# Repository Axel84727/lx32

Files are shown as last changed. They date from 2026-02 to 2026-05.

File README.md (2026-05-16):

# lx32

I built a computer from scratch because ChatGPT told me "no hay huevos." So here we are.

Custom processor, custom PCB, custom compiler. The whole thing.

---

## ok first let me flex

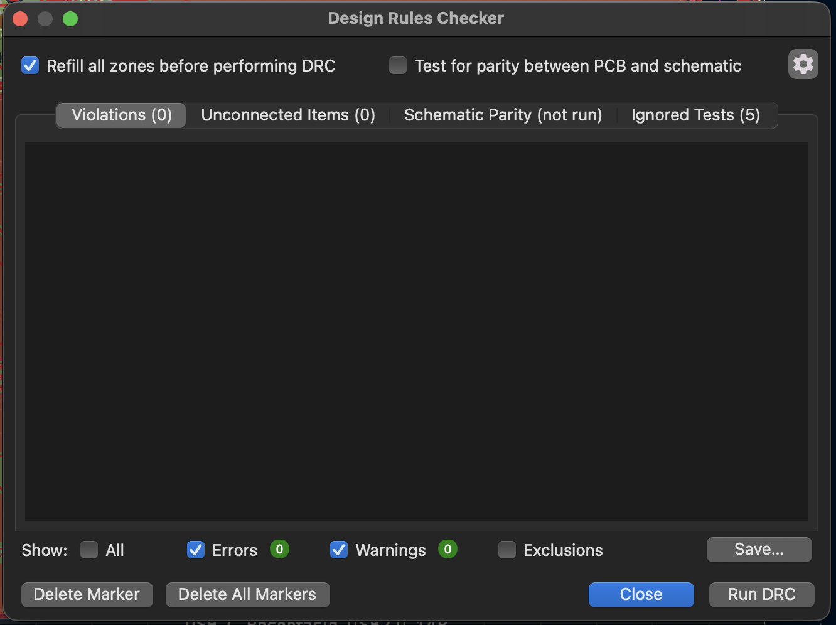
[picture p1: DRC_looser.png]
looser


Zero violations. Zero unconnected items. I cried a little.

(also this is the 5th time I rewrote this README. if it still looks AI-generated I give up)

---

## what is this actually

lx32 is a 32-bit CPU with a custom instruction set, running on a custom PCB, compiled by a custom LLVM backend. You can write C, compile it, and it runs on this thing.

I wanted to actually understand how computers work, not just read about it. So I built one.

The board is 80x60mm, about the size of a credit card. Black soldermask, gold finish.

---

## the board

Here's what it looks like:

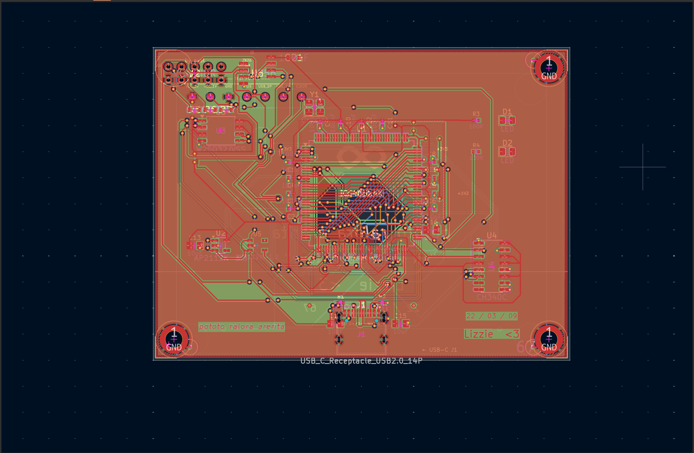
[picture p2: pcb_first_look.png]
first look


The schematics:

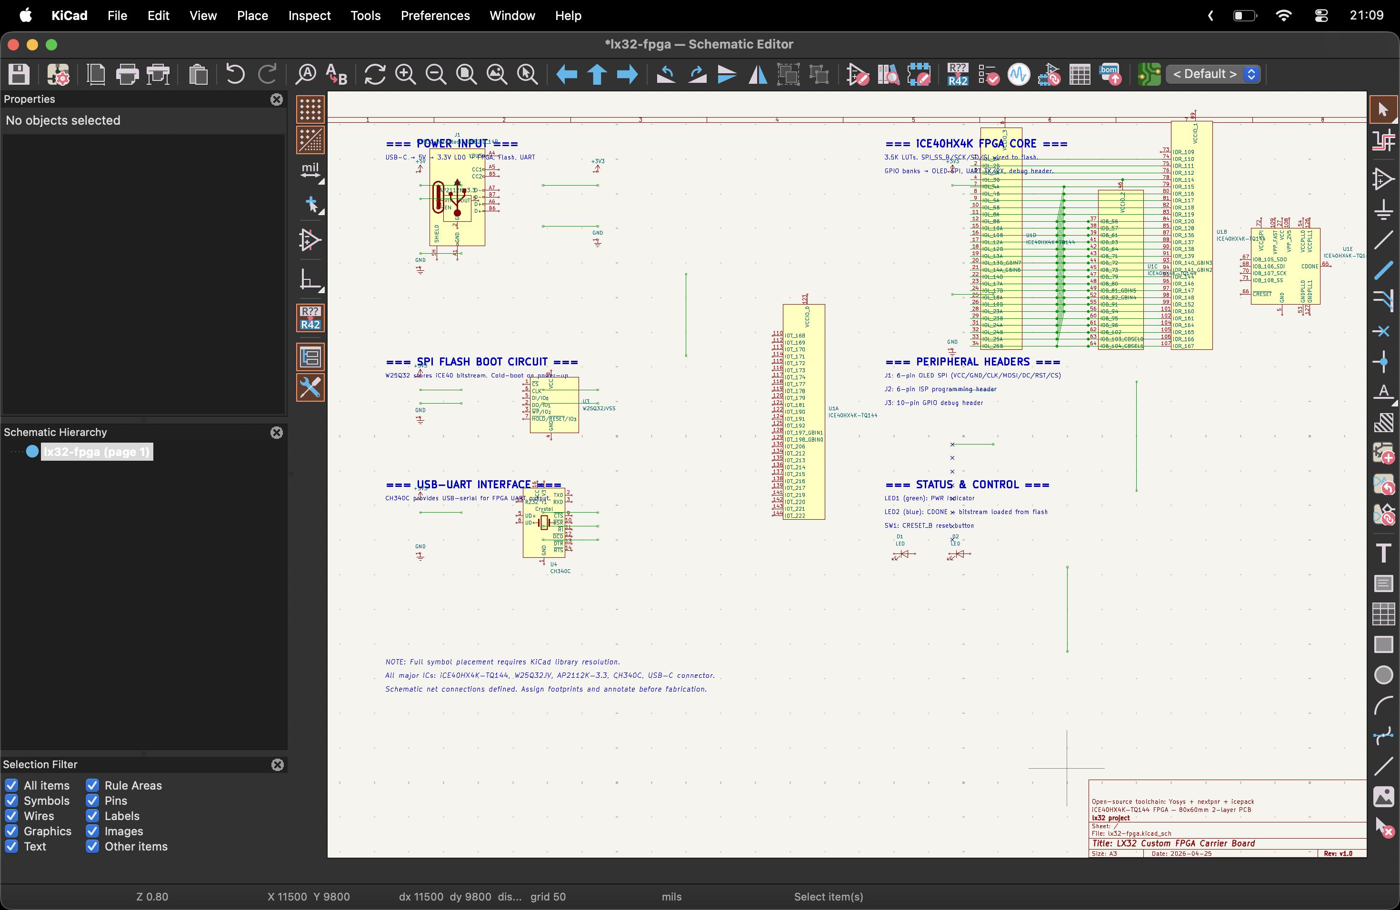
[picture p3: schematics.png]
schematics


Measurements:

Long:
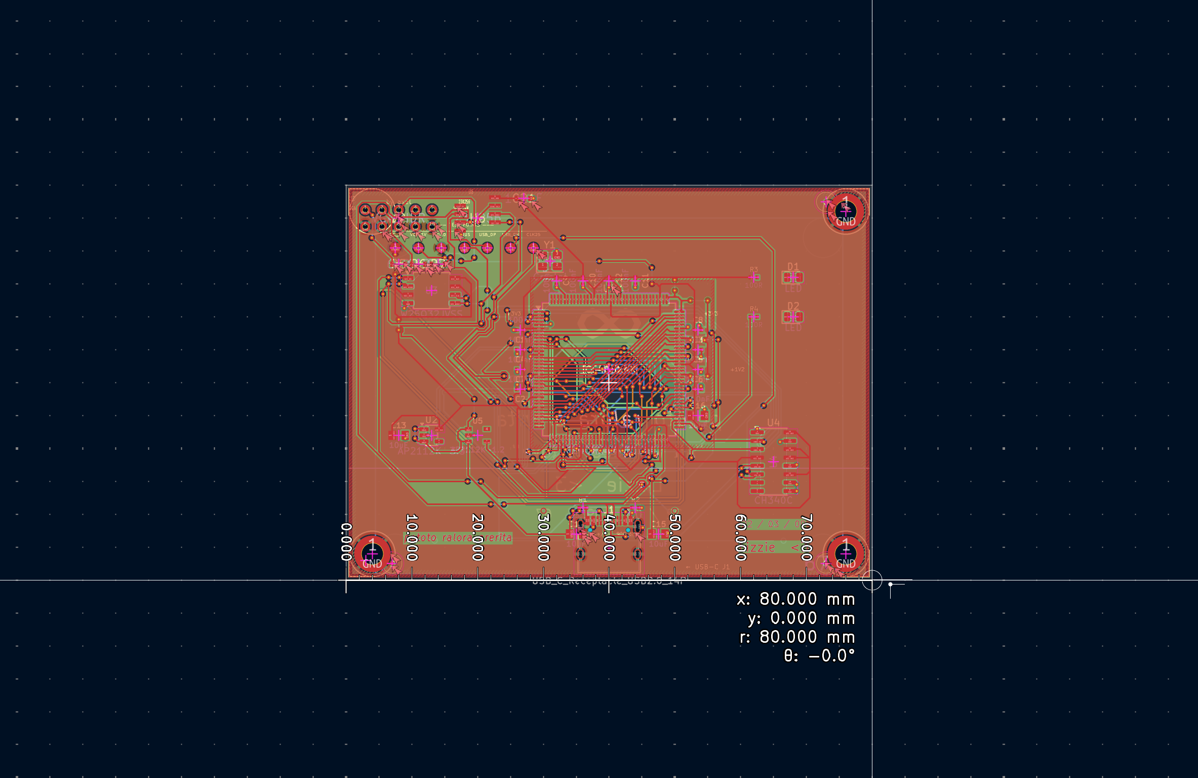
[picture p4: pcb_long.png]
pcb long


Width:
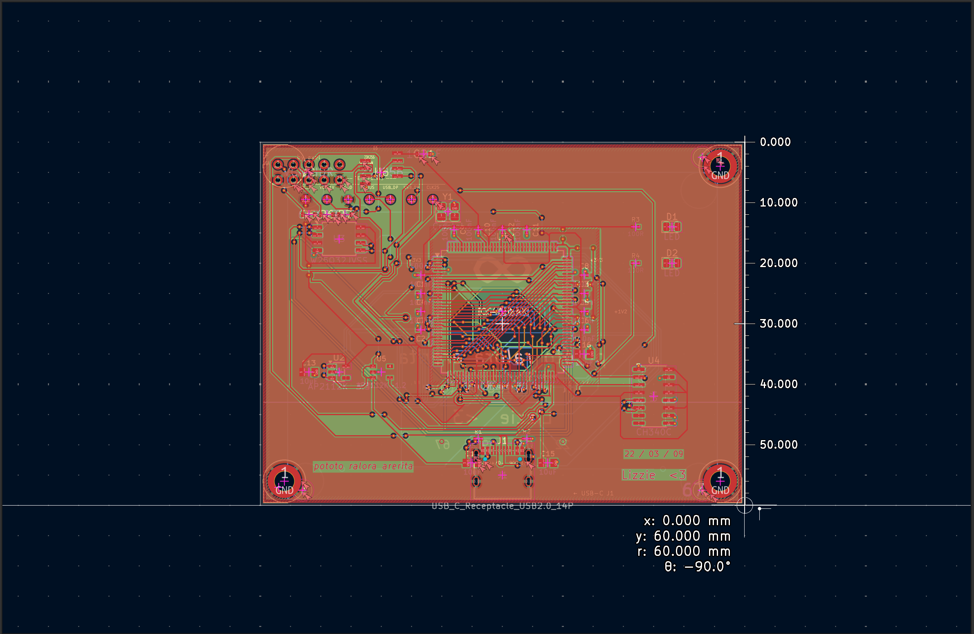
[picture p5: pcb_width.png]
pcb width


Full view:
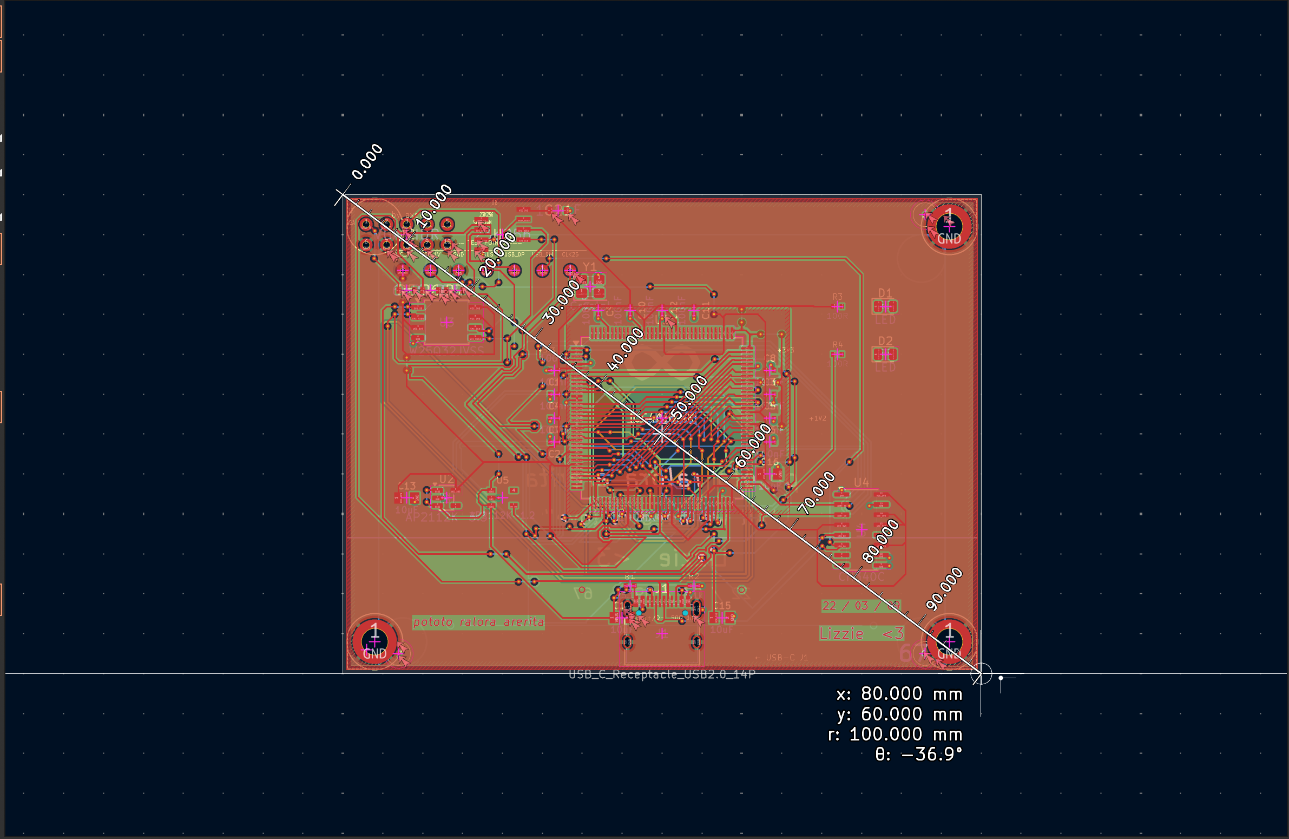
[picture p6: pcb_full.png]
Full picture pcb


The main chip is a Lattice iCE40HX4K FPGA — that's what becomes the processor. I chose it because the toolchain is fully open source (Yosys, nextpnr, icepack).

The rest of the board is USB-C for power and programming, SPI flash so the bitstream loads on power-up, two LDOs for the separate 3.3V and 1.2V rails, a USB-UART bridge to talk to it from my laptop, 32KB of external SRAM, and a VGA header. There's also an OLED that shows register values and the current instruction live, which is the coolest part honestly.

3D render, front:
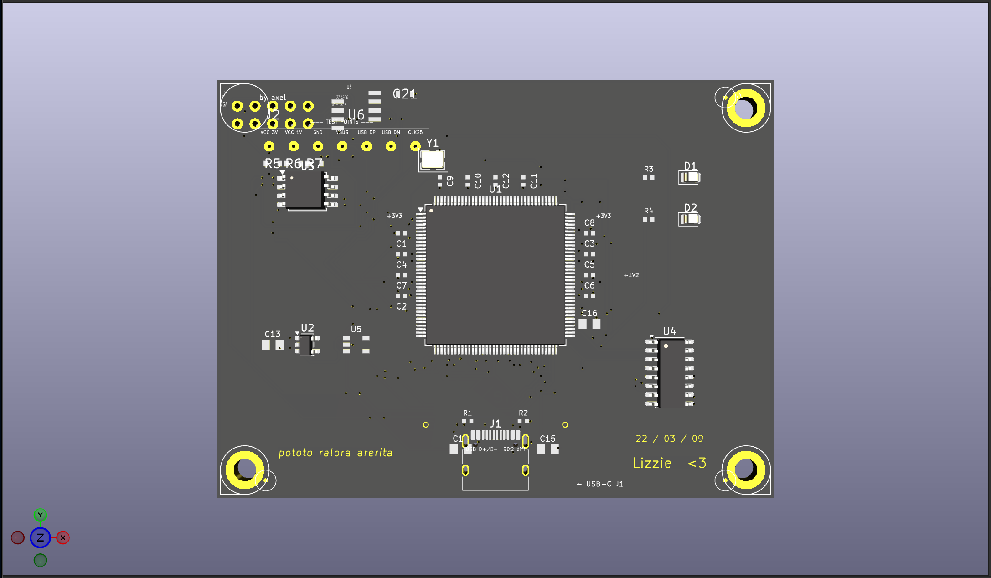
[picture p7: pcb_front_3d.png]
front of pcb


3D render, back:
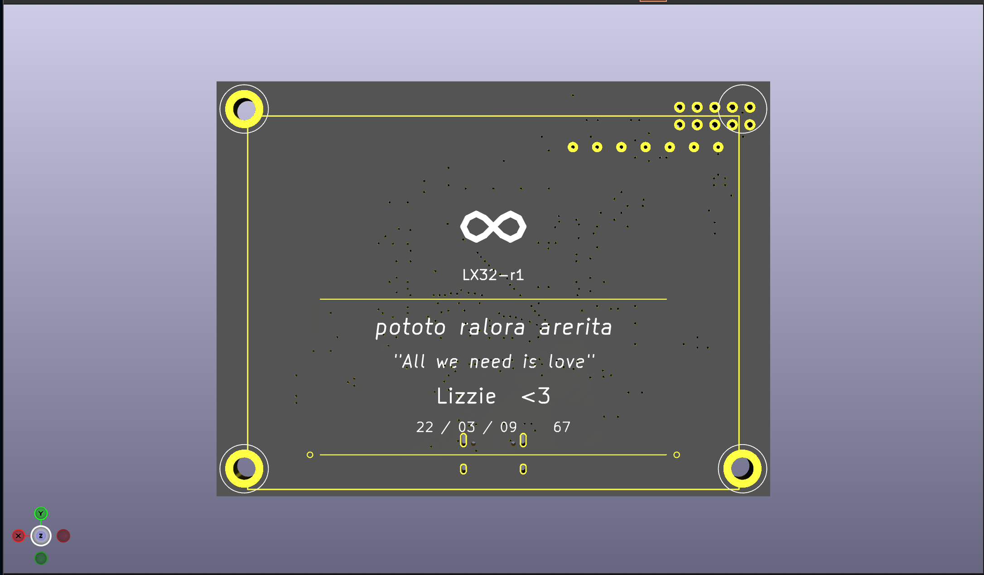
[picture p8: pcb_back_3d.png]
back of pcb


`.STEP` file if you want it: [`lx32-fpga.step`](./cad/lx32-fpga.step)

---

## the processor

32 registers, fixed 32-bit instruction width, single-cycle. I made up the instruction encoding: ADD, SUB, AND, OR, XOR, shifts, loads, stores, branches, jumps, LUI, AUIPC. x0 is hardwired to zero. Everything is in `rtl/` and every module has a spec in `docs/rtl/`.

---

## how I know it works

I wrote a Rust model of the processor, then a fuzzer that fires random instruction sequences through both Verilator and the model at the same time and compares cycle by cycle.

| module | test vectors | result |
|---|---|---|
| ALU | 100,000,000 | passed |
| Branch Unit | 100,000,000 | passed |
| Control Unit | 100,000,000 | passed |
| Register File | 100,000,000 | passed |
| Full System | 100,000,000 | passed |
| **Total** | **1,100,000,000+** | **zero failures** |

Runs in under 75 seconds. I also tortured my laptop with a Python script to run it on loop. There are Coq proofs for some properties and formal verification through sby too.

---

## the compiler

LLVM backend for lx32 — instruction patterns, register file, calling convention. Eight programs compile and run end-to-end: return, pointer store, call chain, branch/loop, compare/assign, pointer walk, iterative fibonacci, recursive fibonacci.

Write C, compile with LLVM, runs on this board.

---

## the gold art

ENIG means the exposed copper comes out gold on black soldermask. I put personal stuff on both sides.

The back has an infinity symbol, *pototo ralora arerita*, *"All we need is love"*, `Lizzie <3`, `22/03/09`, and `67` (that last one I didn't choose, it just ended up there).

It's a working computer and it also has my whole heart on it.

---

## run it yourself

```bash
git clone https://github.com/Axel84727/lx32.git
cd lx32
make setup
```

You'll need: `verilator`, Rust (`cargo`), `coqc`, `sby`, `yosys`, `z3`, `g++`.

```bash
make sim TB=lx32_system_tb    # full system sim
make validate                  # full test suite (1.1B vectors)
make formal-all                # formal proofs
```

---

## BOM

Full BOM: [`lx32-bom.csv`](./lx32-bom.csv)

| Part | Qty | Total |
| :--- | :---: | ---: |
| Custom LX32 PCB (JLCPCB, 4-layer, ENIG, black mask) | 5 | $15.00 |
| Lattice iCE40HX4K-TQ144 | 2 | $19.00 |
| CH340C USB-UART (SOP-16) | 2 | $0.90 |
| W25Q32JVSSIQ SPI Flash 32Mb | 2 | $1.10 |
| AP2112K-3.3TRG1 LDO 3.3V | 2 | $0.60 |
| AP2112K-1.2TRG1 LDO 1.2V | 2 | $0.60 |
| 25MHz Crystal SMD 3225 | 2 | $0.70 |
| USB-C connector SMD | 2 | $0.80 |
| Microchip 23K256 SPI SRAM (SOIC-8) | 2 | $1.20 |
| VGA 2x5 header + 68Ω resistors | -- | $0.76 |
| Passives (caps, resistors, LEDs) | -- | $0.58 |
| 2.54mm pin headers | 1 | $0.80 |
| M3 standoffs + screws | 12 | $1.00 |
| 0.96" OLED display | 1 | $14.22 |
| Jumper wires + breadboard | 1 | $9.89 |
| Shipping JLCPCB to Uruguay | -- | $22.00 |
| Shipping Tiendamia | -- | $38.00 |
| **Total** | | **$127.15** |

---

MIT

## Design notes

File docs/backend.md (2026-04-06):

# Developing Baremetal C Code for LX32

Welcome to the LX32 architecture C development guide! Because LX32 is a custom 32-bit architecture, we rely on a custom LLVM backend to compile our C programs into raw binary machine code that our Verilog/SystemVerilog RTL simulation and formal models can consume.

## Backend Directory Structure

The `tools/lx32_backend/` directory is organized exactly like a standard LLVM backend, to ensure it is extremely modular, clean, and scalable:

*   **`TargetInfo/`**: Registers the LX32 architecture name and triple. 
*   **`core/`**: The main code generator. Handles Register Info, Instruction Info, Frame Lowering, Subtarget features, and Instruction Selection mapping (DAG).
*   **`AsmParser/`**: The component that parses string assembly (`.s`) and maps it into LX32 `MCInst` object representations.
*   **`MCTargetDesc/`**: The Machine Code layer. Emits the final raw binary bits (MCCodeEmitter), Object Files (ELFObjectWriter), and assembly printers.
*   **`TableGen/`**: The `.td` files that declaratively define the LX32 registers, instructions, and calling conventions, generating C++ `.inc` files automatically during the build.
*   **`tests/`**: Contains the compile scripts `compile_baremetal_c.sh` and baremetal C smoke tests.

## Prerequisites

Before you can develop C code for LX32, you need the LX32 LLVM compiler toolchain. The repository automates the entire process of downloading, configuring, and building LLVM with our backend slice cleanly linked into the LLVM tree.

Run the following command from the root of the repository:

```bash
make setup-backend
```

*This will take some time, as it clones LLVM and compiles Clang, LLD (Linker), and the LX32 backend.*

## Writing Your First C Program

Your software will run directly on "bare metal"—there is no operating system, standard library (`libc`), or dynamic memory allocation (`malloc`). You must use freestanding C.

Create your C file, for example, `my_program.c`:

```c
// my_program.c
void main() {
    int *ptr = (int *) 0x1000;
    *ptr = 42; // Store 42 at memory address 0x1000
    while(1);  // Loop forever
}
```

*Important Constraints:*
1. No `#include <stdio.h>` or standard libraries.
2. If you need standard logic (like `memcpy` or `memset`), you will have to implement it yourself.

## Compiling Your C Program

Use the repository's provided `Makefile` target to compile, assemble, and link your code for the LX32 CPU.

```bash
make compile-c PROG=my_program.c
```

### What happens under the hood?

1. **Clang (LLVM Frontend):** Compiles your freestanding C code down to LLVM Intermediate Representation (IR).
2. **llc (LLVM Backend):** Takes the generic IR and precisely maps it to LX32 CPU instructions, generating assembly code (`.s`).
3. **llvm-mc & C Runtime (`crt0.S`):** Your assembly is assembled to an object file (`.o`). It is then bundled with `crt0.S`, which initializes the processor's Stack Pointer and zeroes out the BSS memory segment before calling `main()`.
4. **ld.lld (Linker):** Finally, everything is organized using `tools/lx32_backend/tests/baremetal/link.ld` and packaged into a final `.elf` executable and `.bin` raw image file ready to inject into simulation memory.

## Testing the Toolchain Pipeline

To verify your local LLVM has correctly built and can flawlessly handle the pipeline, run the baremetal smoke tests:

```bash
make test-baremetal
```

This runs specific, edge-case C programs from the `tests/baremetal/programs` folder to ensure the LX32 parser and IR instructions operate flawlessly.

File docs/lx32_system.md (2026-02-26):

# lx32_system.sv

## Description
`lx32_system` is the main processor core, responsible for instruction sequencing, control flow, and connecting the main modules (ALU, registers, memory, etc).

## Ports
- `clk` (input): System clock.
- `rst` (input): Synchronous reset.
- `pc_out` (output, 32 bits): Current program counter value.
- `instr` (input, 32 bits): Current instruction.
- `mem_addr` (output, 32 bits): Data memory address.
- `mem_wdata` (output, 32 bits): Data to write to data memory.
- `mem_rdata` (input, 32 bits): Data read from data memory.
- `mem_we` (output): Data memory write enable.

## Functionality
- Manages the program counter and instruction flow.
- Instantiates and connects control, ALU, register, memory, and branch modules.
- Controls data flow and control signals between modules.

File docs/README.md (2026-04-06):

# LX32 Documentation Orchestration & Deep Reference

## Overview
This README provides a comprehensive guide to the LX32 project documentation. It orchestrates all files in the `docs/` directory, explains their relationships, and offers deep technical reference for the golden model, RTL, tools, and test suites.

---

## Structure
- [Golden Model](golden_model/)
  - [Architecture Packages](golden_model/arch/)
  - [Core Modules](golden_model/core/)
  - [Source Modules](golden_model/source/)
  - [Test Modules](golden_model/tests/)
- [RTL Reference](rtl/)
- [Tools](tools/)

---

## Repository structure

```
.
├── Makefile
├── README.md
├── docs
│   ├── README.md
│   ├── golden_model
│   │   ├── arch
│   │   │   ├── generic
│   │   │   │   └── generic_template_arch.md
│   │   │   ├── lx32_alu_pkg.md
│   │   │   ├── lx32_arch_pkg.md
│   │   │   ├── lx32_branch_pkg.md
│   │   │   ├── lx32_decode_pkg.md
│   │   │   ├── lx32_isa_pkg.md
│   │   │   └── mod.md
│   │   ├── core
│   │   │   ├── alu.md
│   │   │   ├── branch_unit.md
│   │   │   ├── control_unit.md
│   │   │   ├── generic
│   │   │   │   └── generic_template_core.md
│   │   │   ├── imm_gen.md
│   │   │   ├── lsu.md
│   │   │   ├── lx32_system.md
│   │   │   ├── memory_sim.md
│   │   │   ├── mod.md
│   │   │   ├── reg_generic.md
│   │   │   └── register_file.md
│   │   ├── source
│   │   │   ├── bridge.md
│   │   │   ├── cli.md
│   │   │   ├── generic
│   │   │   │   └── generic_template_src.md
│   │   │   ├── lib.md
│   │   │   ├── main.md
│   │   │   ├── program_generator.md
│   │   │   ├── shrinking.md
│   │   │   └── test_runner.md
│   │   └── tests
│   │       ├── common
│   │       │   └── mod.md
│   │       ├── generic
│   │       │   └── generic_template_tests.md
│   │       ├── test_alu.md
│   │       ├── test_branch_unit.md
│   │       ├── test_control_unit.md
│   │       ├── test_imm_gen.md
│   │       ├── test_long_programs.md
│   │       ├── test_lsu.md
│   │       ├── test_lx32_system.md
│   │       ├── test_memory_sim.md
│   │       ├── test_reg_generic.md
│   │       └── test_register_file.md
│   ├── rtl
│   │   ├── arch
│   │   │   ├── generic
│   │   │   │   └── generic_template_arch.md
│   │   │   ├── lx32_alu_pkg.md
│   │   │   ├── lx32_arch_pkg.md
│   │   │   ├── lx32_branch_pkg.md
│   │   │   ├── lx32_decode_pkg.md
│   │   │   └── lx32_isa_pkg.md
│   │   └── core
│   │       ├── alu.md
│   │       ├── branch_unit.md
│   │       ├── control_unit.md
│   │       ├── generic
│   │       │   └── generic_template_core.md
│   │       ├── imm_gen.md
│   │       ├── lsu.md
│   │       ├── lx32_system.md
│   │       ├── memory_sim.md
│   │       ├── reg_generic.md
│   │       └── register_file.md
│   └── tools
│       ├── build.md
│       ├── demo.md
│       ├── setup.md
│       └── validator_make_usage.md
├── rtl
│   ├── arch
│   │   ├── lx32_alu_pkg.sv
│   │   ├── lx32_arch_pkg.sv
│   │   ├── lx32_branch_pkg.sv
│   │   ├── lx32_decode_pkg.sv
│   │   └── lx32_isa_pkg.sv
│   └── core
│       ├── alu.sv
│       ├── branch_unit.sv
│       ├── control_unit.sv
│       ├── imm_gen.sv
│       ├── lsu.sv
│       ├── lx32_system.sv
│       ├── memory_sim.sv
│       ├── reg_generic.sv
│       └── register_file.sv
├── tb
│   ├── arch
│   │   ├── branches_pkg_tb.sv
│   │   ├── lx32_arch_pkg_tb.sv
│   │   └── lx32_pkg_tb.sv
│   └── core
│       ├── alu_tb.sv
│       ├── branch_unit_tb.sv
│       ├── control_unit_tb.sv
│       ├── imm_gen_tb.sv
│       ├── lsu_tb.sv
│       ├── lx32_system_tb.sv
│       ├── memory_sim_tb.sv
│       ├── reg_generic_tb.sv
│       └── register_file_tb.sv
└── tools
    ├── lx32_formal
    │   ├── README.md
    │   ├── LX32_ALU.v
    │   ├── LX32_Arch.v
    │   ├── LX32_Branch.v
    │   ├── LX32_Control.v
    │   ├── LX32_Decode.v
    │   ├── LX32_RegisterFile.v
    │   ├── LX32_Safety.v
    │   ├── LX32_Step.v
    │   ├── lec
    │   │   ├── alu_eq.ys
    │   │   ├── alu_spec.sv
    │   │   ├── branch_eq.ys
    │   │   └── branch_unit_spec.sv
    │   └── sva
    │       ├── control_unit_sva.sby
    │       ├── control_unit_sva.sv
    │       ├── register_file_sva.sby
    │       └── register_file_sva.sv
    ├── lx32_validator
    │   ├── Cargo.lock
    │   ├── Cargo.toml
    │   ├── build.rs
    │   ├── demo.sh
    │   ├── src
    │   │   ├── bridge.cpp
    │   │   ├── cli.rs
    │   │   ├── lib.rs
    │   │   ├── main.rs
    │   │   ├── models
    │   │   │   ├── arch
    │   │   │   │   ├── lx32_alu_pkg.rs
    │   │   │   │   ├── lx32_arch_pkg.rs
    │   │   │   │   ├── lx32_branch_pkg.rs
    │   │   │   │   ├── lx32_decode_pkg.rs
    │   │   │   │   ├── lx32_isa_pkg.rs
    │   │   │   │   └── mod.rs
    │   │   │   ├── core
    │   │   │   │   ├── alu.rs
    │   │   │   │   ├── branch_unit.rs
    │   │   │   │   ├── control_unit.rs
    │   │   │   │   ├── imm_gen.rs
    │   │   │   │   ├── lsu.rs
    │   │   │   │   ├── lx32_system.rs
    │   │   │   │   ├── memory_sim.rs
    │   │   │   │   ├── mod.rs
    │   │   │   │   ├── reg_generic.rs
    │   │   │   │   └── register_file.rs
    │   │   │   └── mod.rs
    │   │   ├── program_generator.rs
    │   │   ├── shrinking.rs
    │   │   └── test_runner.rs
    │   └── tests
    │       ├── common
    │       │   └── mod.rs
    │       ├── test_alu.rs
    │       ├── test_branch_unit.rs
    │       ├── test_control_unit.rs
    │       ├── test_imm_gen.rs
    │       ├── test_long_programs.rs
    │       ├── test_lsu.rs
    │       ├── test_lx32_system.rs
    │       ├── test_memory_sim.rs
    │       ├── test_reg_generic.rs
    │       └── test_register_file.rs
    └── setup.sh
```
---

## Golden Model Documentation
### Architecture Packages (`golden_model/arch/`)
- **lx32_alu_pkg.md**: Canonical ALU operation types, enums, and constants. Used for ALU, control, decode. Mirrors RTL.
- **lx32_arch_pkg.md**: Fundamental architectural types, constants, and parameters. Used for instruction formats, register mapping, memory layout. Mirrors RTL.
- **lx32_branch_pkg.md**: Branch operation types, enums, and constants. Used for branch unit, control, decode. Mirrors RTL.
- **lx32_decode_pkg.md**: Immediate extraction logic, decode parameters, and functions. Used for instruction decoding and immediate generation. Mirrors RTL.
- **lx32_isa_pkg.md**: Opcode enumerations and instruction class encodings. Used for instruction decoding and pipeline control. Mirrors RTL.
- **mod.md**: Central repository, re-exports all architecture packages for unified access.

### Core Modules (`golden_model/core/`)
- **alu.md**: Implements ALU for LX32 base operations. Reference for arithmetic, logical, shift, and comparison. Unit tests: `test_alu.rs`.
- **branch_unit.md**: Branch evaluation logic for LX32 base branch conditions. Unit tests: `test_branch_unit.rs`.
- **control_unit.md**: Instruction decode logic, main control, ALU operation refinement. Unit tests: `test_control_unit.rs`.
- **imm_gen.md**: Immediate generation logic for LX32 base instructions. Unit tests: `test_imm_gen.rs`.
- **lsu.md**: Load/Store Unit, single-cycle memory operations. Unit tests: `test_lsu.rs`.
- **lx32_system.md**: Integrates all core sub-modules, single-cycle execution. Unit tests: `test_lx32_system.rs`.
- **memory_sim.md**: Dual-port simulation memory, 4KB, word-aligned. Unit tests: `test_memory_sim.rs`.
- **reg_generic.md**: Parameterizable synchronous register, async reset, clock enable. Unit tests: `test_reg_generic.rs`.
- **register_file.md**: Register file, 32 registers, dual async read, sync write. Unit tests: `test_register_file.rs`.
- **mod.md**: Central module, re-exports all core modules for integration.

### Source Modules (`golden_model/source/`)
- **bridge.md**: C++ hardware bridge, FFI interface between Rust and Verilated hardware model.
- **cli.md**: CLI argument parsing, unified configuration for test orchestration.
- **lib.md**: Core Rust library interface, exposes models, program generation, shrinking, FFI bindings.
- **main.md**: Main orchestrator, coordinates validation tests, manages seeds, long program generation, shrinking.
- **program_generator.md**: Generates long instruction sequences for comprehensive hardware testing.
- **shrinking.md**: Test case shrinker, reduces failing cases to minimal reproducible examples.
- **test_runner.md**: Coordinates execution of all validation test suites, delegates to individual test modules.

### Test Modules (`golden_model/tests/`)
- **test_alu.md**: Validates ALU, parameterized unit tests, state comparison, property-oriented fuzzing.
- **test_branch_unit.md**: Validates branch unit, parameterized unit tests, state comparison.
- **test_control_unit.md**: Validates control unit, parameterized unit tests, state comparison.
- **test_imm_gen.md**: Validates immediate generator, parameterized unit tests, state comparison.
- **test_lsu.md**: Validates LSU, parameterized unit tests, state comparison.
- **test_lx32_system.md**: Validates overall system, parameterized unit tests, state comparison.
- **test_memory_sim.md**: Validates memory simulation, parameterized unit tests, state comparison.
- **test_reg_generic.md**: Validates generic register, parameterized unit tests, state comparison.
- **test_register_file.md**: Validates register file, parameterized unit tests, state comparison.
- **test_long_programs.md**: Validates with long, randomly generated instruction sequences, integration tests, shrinking.

---

## RTL Reference Documentation (`rtl/`)
- Mirrors golden model structure for architecture and core modules.
- Provides SystemVerilog reference for hardware equivalence.
- See `rtl/arch/` and `rtl/core/` for package and module documentation.

---

## Tools Documentation (`tools/`)
- **build.md**: Explains `build.rs` script, integrates Verilator C++ code with Rust, static library compilation.
- **demo.md**: Demonstrates advanced validation features, reproducible seeds, CLI help, long program testing.
- **setup.md**: Environment setup, dependency checks, bridge generation, validator compilation, initial validation.
- **validator_make_usage.md**: Makefile guide for simulation and validation, target descriptions, CLI options, custom scenarios.
- **coq_workflow.md**: Practical Coq build and validation workflow.
- **isa_formal_equations.md**: Full ISA equation sheet and canonical closure theorem.

---

## Deep Technical Reference & Orchestration
### Integration & Workflow
- The LX32 validator is orchestrated via the CLI and Makefile, with modular Rust and C++ components.
- The golden model and RTL are cross-validated via test suites and property-oriented fuzzing.
- Shrinking engine reduces failing cases for triage.
- All modules are unit tested and regression tested for hardware/software equivalence.

### How to Use
- Start with [setup.md](tools/setup.md) for environment preparation.
- Use [validator_make_usage.md](tools/validator_make_usage.md) for Makefile targets and CLI options.
- Explore [demo.md](tools/demo.md) for advanced features and reproducible validation.
- Dive into [golden_model/core/](golden_model/core/) and [golden_model/arch/](golden_model/arch/) for module and package details.
- Reference [golden_model/tests/](golden_model/tests/) for test design and validation principles.
- Compare with [rtl/](rtl/) for hardware equivalence.

### License
All documentation and code are MIT licensed.

---

## Links & References
- [Golden Model Source](../tools/lx32_validator/src/)
- [RTL Source](../rtl/)
- [Makefile](../Makefile)
- [Setup Script](../tools/setup.sh)
- [Demo Script](../tools/lx32_validator/demo.sh)

---

## Contact & Contribution
- For questions, see [README.md](../README.md) in project root.
- Contributions welcome via pull requests.

---

## Revision
- Last updated: March 8, 2026

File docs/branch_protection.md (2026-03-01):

# GitHub Branch Protection and CI Configuration Guide

This document explains how to configure GitHub to require all CI checks to pass before merging PRs to `main`.

## Workflow Overview

Three workflows are automatically triggered on each pull request to `main`:

1. **test-golden-model.yml** - Runs all 9 Rust golden model validation tests
2. **test-systemverilog.yml** - Runs all 9 SystemVerilog testbenches via Make
3. **ci.yml** - Master workflow that requires both above workflows to pass

## Setting Up Branch Protection

To enforce that PRs to `main` cannot be merged without passing CI:

### Step 1: Go to Repository Settings
1. On GitHub, go to your repository
2. Click on **Settings** tab
3. Select **Branches** from left sidebar

### Step 2: Add Branch Protection Rule

1. Click **Add rule**
2. Enter `main` in the **Branch name pattern** field
3. Enable the following protections:

#### Required Checks
- [x] **Require status checks to pass before merging**
  - Select these status checks:
    - `PR Gate - All Tests Required` (the master check)
    - Or individually:
      - `Golden Model Tests`
      - `SystemVerilog Testbenches`

#### Additional Protections (Recommended)
- [x] **Require a pull request before merging**
  - Reviews required: `1`
  - Dismiss stale pull request approvals when new commits are pushed: Yes
  - Require code review from code owners: Yes (if using CODEOWNERS)

- [x] **Require branches to be up to date before merging**
  - This ensures PR is tested against latest main

- [x] **Require status checks to pass before merging**
- [ ] **Require conversation resolution before merging**

#### Merge Restrictions (Optional)
- Allow squash merging: Yes
- Allow rebase merging: Yes
- Allow merge commits: No (enforces clean history)

- [x] **Restrict who can push to matching branches**
  - Allow: Admins and repository owners

- [x] **Require dismissal of stale reviews on new push**

### Step 3: Click **Create** or **Save changes**

## What Happens When a PR is Created

1. **Author creates PR** to `main`
2. **Workflows automatically trigger:**
   - `test-golden-model.yml` runs all 9 Rust tests in parallel
   - `test-systemverilog.yml` runs all 9 SystemVerilog testbenches in parallel
   - `ci.yml` waits for both and enforces gate
3. **Results appear on PR:**
   - Green ✅ checkmark = all tests passed, can merge
   - Red ❌ X = tests failed, cannot merge until fixed
4. **Author must fix failing tests** and push new commits
5. **Tests re-run automatically** on each push
6. **Once all pass**, merge button becomes available

## Workflow Details

### Golden Model Tests (test-golden-model.yml)

Runs in parallel:
- `test_alu` - ALU functionality (3000 iterations)
- `test_branch_unit` - Branch logic (10000 iterations)
- `test_control_unit` - Control signals (500 iterations)
- `test_imm_gen` - Immediate generation (2000 iterations)
- `test_lsu` - Memory operations (2000 iterations)
- `test_memory_sim` - Memory model (1000 iterations)
- `test_reg_generic` - Register template (2000 iterations)
- `test_register_file` - Register file (2000 iterations)
- `test_lx32_system` - Full system (500 iterations)

**Fails if:** Any single test module fails

### SystemVerilog Testbenches (test-systemverilog.yml)

Runs in parallel (via Makefile):
- `alu_tb` - ALU testbench
- `branch_unit_tb` - Branch unit testbench
- `control_unit_tb` - Control unit testbench
- `imm_gen_tb` - Immediate generator testbench
- `lsu_tb` - LSU testbench
- `memory_sim_tb` - Memory simulator testbench
- `reg_generic_tb` - Register generic testbench
- `register_file_tb` - Register file testbench
- `lx32_system_tb` - Full system testbench

**Fails if:** Any single testbench fails

### CI Gate (ci.yml)

Master workflow that:
1. Calls `test-golden-model.yml`
2. Calls `test-systemverilog.yml` 
3. Runs `pr-gate` job that waits for both
4. Reports overall status as **"PR Gate - All Tests Required"**

## Merging Behavior

With branch protection enabled:

| Scenario | Can Merge? | Why |
|---|---|-----|
| All tests pass | ✅ Yes | All status checks green |
| One test fails | ❌ No | Status check red, blocks merge |
| Tests still running | ⏳ Pending | Cannot merge until complete |
| Author pushes fix | ✅ Tests re-run | New commit triggers workflows |
| Force push attempted | ❌ Rejected | Branch protection prevents it |

## Verifying Configuration

To verify branch protection is working:

1. When you create a test PR, you should see workflows running
2. In PR checks section, you'll see:
   - ⏳ Checks running (initial)
   - ❌ Checks failed (if test fails)
   - ✅ Checks passed (if all pass)
3. Merge button is grayed out until all pass

## Troubleshooting

### Workflows not running?
- Check `.github/workflows/` directory exists
- Verify `.yml` files are in that directory
- Check file syntax with `yamllint` locally

### Want to disable a test temporarily?
1. Edit the workflow file
2. Comment out the test from the `matrix.test` list
3. Push to feature branch (doesn't affect CI)
4. This won't block PRs

### Need to merge without passing tests?
1. Admins can dismiss failed status checks
2. Go to PR review section → dismiss checks
3. This logs the bypass for audit trail

### Making a workflow more permissive?
- Edit the workflow file
- Commit to `main` directly or via approved PR
- New runs use updated workflow

### Making a workflow stricter?
- Add new tests to the `matrix.test` list
- Only affects new PRs created after merge

## CI Performance

Expected run times:
- **Golden Model Tests:** 6-8 minutes (all 30,500 iterations)
- **SystemVerilog Testbenches:** 8-12 minutes (all 9 testbenches)
- **Total CI time:** ~15 minutes (runs in parallel)

**Cost:** Free (GitHub Actions provides 2000 free minutes/month for private repos)

## Examples

### Example PR Success
```
✅ Pull request checks
├── ✅ test-golden-model.yml (11 passed)
│   ├── ✅ test_alu
│   ├── ✅ test_branch_unit
│   ├── ... (all 9 modules)
│   └── ✅ All Tests Passed
├── ✅ test-systemverilog.yml (9 passed)
│   ├── ✅ alu_tb
│   ├── ✅ branch_unit_tb
│   ├── ... (all 9 testbenches)
│   └── ✅ All Testbenches Passed
└── ✅ PR Gate - All Tests Required

[Merge button AVAILABLE]
```

### Example PR Failure (one test fails)
```
✅ Pull request checks
├── ❌ test-golden-model.yml (8 passed, 1 failed)
│   ├── ✅ test_alu
│   ├── ❌ test_branch_unit (FAILED)
│   ├── ✅ test_control_unit
│   └── ... 
├── ⏳ test-systemverilog.yml (waiting)
└── ❌ PR Gate - All Tests Required (blocked)

[Merge button DISABLED]
Message: "1 check failed"
```

## Summary

This CI setup ensures:

1. ✅ **All tests run on every PR** - both Rust golden models and SystemVerilog testbenches
2. ✅ **Parallel execution** - faster feedback (both workflows run simultaneously)
3. ✅ **Fail-fast** - if any test fails, PR cannot merge
4. ✅ **Clear status** - developers see exactly which test failed
5. ✅ **Automated enforcement** - no manual oversight needed
6. ✅ **Audit trail** - all test runs logged in workflow history

Once configured, branch protection ensures `main` always contains code that passes all 18 test modules (9 Rust + 9 SystemVerilog).

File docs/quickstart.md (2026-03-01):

This guide covers how to build and run the LX32 processor simulator with the Rust golden model validation framework.

## Prerequisites

Before starting, ensure you have:

- **Verilator 5.044+** installed and in PATH

- **Rust toolchain** (stable) for Cargo

- **C++ compiler** (g++ or clang++)

- **SystemVerilog RTL files** in `rtl/` directory

- **Rust model files** in `tools/lx32_validator/src/models/`

### Checking Prerequisites

```bash

# Check Verilator

verilator --version

# Check Rust

cargo --version

rustc --version

# Check C++ compiler

g++ --version

```

## Project Structure

```

lx32/

├── rtl/ # SystemVerilog RTL source

│ ├── arch/ # Architecture packages

│ │ ├── lx32_arch_pkg.sv # Configuration (XLEN, REG_COUNT, PC_WIDTH)

│ │ ├── lx32_isa_pkg.sv # Instruction set opcodes

│ │ ├── lx32_decode_pkg.sv # Immediate extraction

│ │ ├── lx32_alu_pkg.sv # ALU operation codes

│ │ └── lx32_branch_pkg.sv # Branch operation codes

│ └── core/ # Core modules

│ ├── lx32_system.sv # Top-level processor

│ ├── register_file.sv # Register file (32 x 32-bit)

│ ├── alu.sv # Arithmetic Logic Unit

│ ├── branch_unit.sv # Branch condition evaluator

│ ├── control_unit.sv # Instruction decoder

│ ├── imm_gen.sv # Immediate generator

│ ├── lsu.sv # Load/Store Unit

│ ├── memory_sim.sv # Memory simulation

│ └── reg_generic.sv # Generic register cell

├── tb/ # SystemVerilog testbenches

│ ├── arch/ # Architecture-level tests

│ └── core/ # Core module tests

├── tools/lx32_validator/ # Rust-based golden model framework

│ ├── src/

│ │ ├── main.rs # Test orchestration

│ │ ├── models/ # Golden model implementations

│ │ │ ├── arch/ # Architecture packages (Rust)

│ │ │ └── core/ # Core module models (Rust)

│ │ ├── bridge.cpp # FFI bridge to Verilator

│ │ └── lib.rs # Library exports

│ ├── tests/ # Fuzzer test modules

│ │ ├── test_alu.rs

│ │ ├── test_branch_unit.rs

│ │ ├── test_control_unit.rs

│ │ ├── test_lsu.rs

│ │ ├── test_imm_gen.rs

│ │ ├── test_memory_sim.rs

│ │ ├── test_reg_generic.rs

│ │ ├── test_register_file.rs

│ │ └── test_lx32_system.rs

│ ├── Cargo.toml

│ └── build.rs

├── Makefile # Build automation

├── README.md # Project overview

```

## Build Steps

### Step 1: Generate RTL Library with Verilator

```bash

cd /path/to/lx32

make librust

```

This command:

1. Runs Verilator in library mode to generate C++ simulation models from RTL

2. Compiles the C++ FFI bridge that connects Rust to the Verilator model

3. Creates `.sim/lx32_lib/` directory with generated files

**Output:** `lx32_bridge` static library linking against Verilator

### Step 2: Build Rust Validator Framework

```bash

cd tools/lx32_validator

cargo build --release

```

This command:

1. Reads `Cargo.toml` and fetches dependencies (rand crate)

2. Runs `build.rs` which:

- Locates the Verilator-generated files from step 1

- Compiles C++ bridge code

- Links everything into a Rust-compatible library

3. Compiles all Rust model code

4. Produces executable in `target/release/`

**Output:** Binary ready for test execution

### Step 3: Run the Fuzzer Test Suite

```bash

cd tools/lx32_validator

# Full release build with all optimizations

cargo run --release

# Or with Rust debug checks (slower)

cargo run

# Run specific test module only

cargo test test_alu --release -- --nocapture

cargo test test_register_file --release -- --nocapture

```

## Common Commands

### Running All Tests with Logging

```bash

cd tools/lx32_validator

cargo run --release 2>&1 | tee fuzzer_results.log

```

This:

- Runs the full test suite

- Captures all output to both terminal and `fuzzer_results.log`

- Validates RTL against golden model for 9 core components

- Tests run for specific iteration counts (see below)

### Running Individual Component Tests

```bash

# ALU tests (3000 iterations)

cargo test test_alu --release -- --nocapture --test-threads=1

# Branch unit tests (10000 iterations)

cargo test test_branch_unit --release -- --nocapture --test-threads=1

# Register file tests (2000 iterations)

cargo test test_register_file --release -- --nocapture --test-threads=1

# Full processor system (500 iterations)

cargo test test_lsx32_system --release -- --nocapture --test-threads=1

```

### Cleaning Build Artifacts

```bash

# Clean Rust builds only

cargo clean

# Clean everything (RTL and Rust)

make clean && cargo clean

# Preserve RTL library, clean only Rust

cd tools/lx32_validator && cargo clean

```

## Understanding Test Output

When running tests, you'll see:

```

===== LX32 FULL HARDWARE VALIDATION ======

======= STARTING ALU FUZZER ========

Iterations: 3000

RD Range: (1, 32)

RS1 Range: (0, 32)

IMM Range: (0, 4096)

[ 0] ADD | RS1: 0x12345678 RS2: 0xABCDEF00 | Result: 0xBE027578 | MATCH

[ 1] SLL | RS1: 0x00000001 RS2: 0x00000003 | Result: 0x00000008 | MATCH

...

[2999] SRA | RS1: 0xFFFFFFF0 RS2: 0x00000002 | Result: 0xFFFFFFFC | MATCH

===== ALU FUZZER PASSED ======

======= STARTING BRANCH UNIT FUZZER ========

...

===== ALL TESTS PASSED SUCCESSFULLY ======

```

Each test displays:

- **Iteration count** in brackets

- **Operation type** (ADD, SLL, etc. for ALU)

- **Input/Output values** in hex

- **Status** (MATCH if RTL == golden model)

If a mismatch occurs:

- Test **panics** with detailed error information

- Shows iteration number, expected vs. actual values

- Indicates which signals mismatched

## Build Environment Variables

### Custom Verilator Installation

If Verilator is not in the default location, set:

```bash

export VERILATOR_ROOT=/path/to/verilator/share/verilator

# Then rebuild

cargo clean && cargo build --release

```

Default paths tried (in order):

1. Environment variable `VERILATOR_ROOT`

2. `/opt/homebrew/opt/verilator/share/verilator` (Homebrew macOS)

3. `/usr/share/verilator` (Linux system package)

### Release vs Debug Builds

```bash

# Optimized (recommended for fuzzers)

cargo build --release

cargo run --release

# Debug with extra checks (slower but safer)

cargo build

cargo run

```

Release builds run approximately 3-5x faster than debug builds.

## File Regeneration

If you modify RTL files, regenerate the library:

```bash

make librust # Regenerates Verilator C++ outputs

cargo build --release # Rebuilds linking against new outputs

```

If you modify Rust model files:

```bash

cargo build --release

```

Cargo automatically detects changes and rebuilds only affected components.

## Troubleshooting

### Error: "RTL build directory ... not found"

**Problem:** Verilator library generation failed

**Solution:**

```bash

make clean # Clean previous artifacts

make librust # Regenerate from scratch

cargo clean # Clear Rust cache

cargo build --release

```

### Error: "VERILATOR_ROOT" not set

**Problem:** Can't find Verilator installation

**Solution:**

```bash

# Find Verilator installation

which verilator

# If found, set VERILATOR_ROOT to the share/verilator directory

export VERILATOR_ROOT=$(dirname $(dirname $(which verilator)))/share/verilator

# Check it's correct

ls $VERILATOR_ROOT/include/verilated.h

# Rebuild

cargo clean && cargo build --release

```

### Error: Compilation fails with C++ errors

**Problem:** C++ bridge or Verilator headers don't match

**Solution:**

```bash

# Clean completely and rebuild

make clean

make librust

cd tools/lx32_validator

cargo clean

cargo build --release

```

### Tests hang or take very long

**Problem:** Debug build is slow, or system resources exhausted

**Solution:**

```bash

# Use release builds (10x faster)

cargo run --release

# Reduce iteration counts in tests (edit main.rs)

# Or run individual tests with fewer iterations

```

## Resources

- **RTL Design**: See [rtl/](rtl/) and [docs/](docs/) for module descriptions

- **Golden Models**: See [src/models/](tools/lx32_validator/src/models/) for Rust implementations

- **Test Framework**: See [tests/](tools/lx32_validator/tests/) for fuzzer structure

- **Verilator Documentation**: https://verilator.org/

- **RISC-V ISA Spec**: https://riscv.org/technical/specifications/

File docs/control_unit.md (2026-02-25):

# control_unit.sv

## Description
`control_unit` generates the control signals required for instruction execution by decoding the opcode and other instruction fields.

## Ports
- `opcode` (input, 7 bits): Instruction opcode.
- `funct3` (input, 3 bits): funct3 field from instruction.
- `funct7_5` (input, 1 bit): Bit 5 of funct7.
- `reg_write` (output): Register write enable.
- `alu_src` (output): Selects ALU source.
- `mem_write` (output): Memory write enable.
- `result_src` (output, 2 bits): Selects result source.
- `branch` (output): Branch operation enable.
- `alu_control` (output): ALU operation select.

## Functionality
- Decodes the opcode and generates control signals for the datapath.
- Determines ALU operation and data flow.

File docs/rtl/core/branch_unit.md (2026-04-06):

# branch_unit — RTL Core Module Documentation

## Overview

Evaluates branch conditions for the LX32 processor, supporting all LX32 base branch types. Implements execute stage branch logic. Connects to control unit and ALU.

---

## Design Principles

- Canonical RTL implementation for branch evaluation.
- Parameterization and type safety (WIDTH, branch_op_e).
- Clear signal semantics and modular structure.
- Robust, synthesis-friendly design with formal-verification readiness.

---

## Port Interface & Parameters

| Signal | Direction | Type | Description |
|---|---|---|---|
| src_a | input | [WIDTH-1:0] | First operand |
| src_b | input | [WIDTH-1:0] | Second operand |
| is_branch | input | logic | Enables branch logic |
| branch_op | input | lx32_branch_pkg::branch_op_e| Branch operation selector |
| branch_taken  | output | logic | Branch comparison result |

| Parameter | Default | Type | Description |
|---|---|---|---|
| WIDTH | 32 | integer | Data width |

---

## Content & Structure

- Implements branch comparison logic for execute stage.
- Uses `lx32_branch_pkg` for operation encoding.
- Handles reset, clocking, and control signal propagation.

---

## Integration

- Connects to control unit, ALU, and pipeline datapath.
- Forms part of the processor pipeline and interfaces with system-level signals.

---

## References

- RTL source: [`rtl/core/branch_unit.sv`](../../rtl/core/branch_unit.sv)

---

## License

MIT

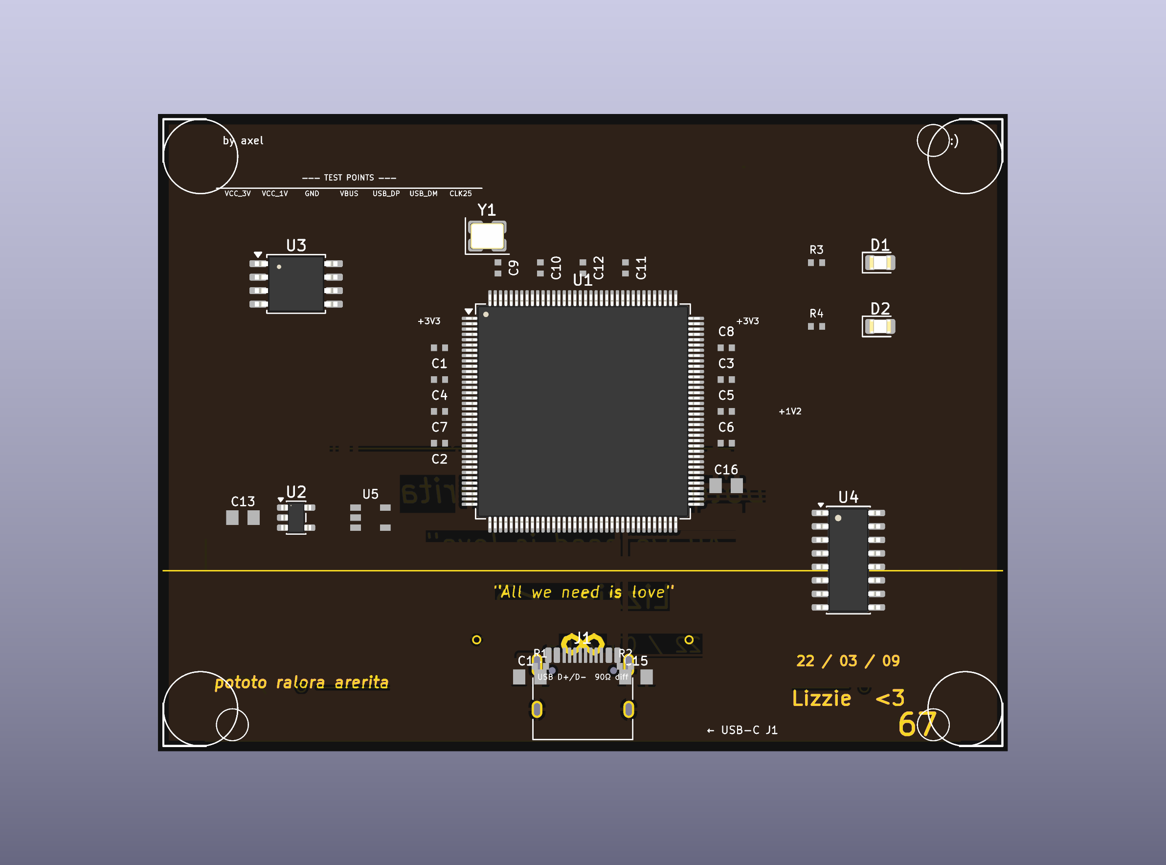
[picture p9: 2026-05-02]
cad_img.png

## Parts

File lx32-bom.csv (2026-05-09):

Name | Purpose | Quantity | Unit Price (USD) | Total (USD) | Link | Distributor
Custom LX32 PCB (JLCPCB 4-layer 80x60mm — ENIG Black Mask) | Carrier board fabrication. 2-layer FR4, ENIG surface finish (required for gold artwork), black soldermask, white silkscreen. 5-board minimum run. | 5 | 3.00 | 15.00 | https://jlcpcb.com | JLCPCB
Lattice iCE40HX4K-TQ144 | Main FPGA for lx32 soft-core synthesis. 3.5K LUTs, 80KB block RAM, TQ144 QFP package. Open-source toolchain (Yosys/nextpnr) compatible. | 2 | 9.50 | 19.00 | https://www.lcsc.com/product-detail/FPGAs_Lattice-iCE40HX4K-TQ144_C5349789.html | LCSC
CH340C USB-UART (SOP-16) | USB-to-UART bridge for FPGA programming interface. Avoids FTDI licensing issues. Well-supported on Linux/macOS without drivers. | 2 | 0.45 | 0.90 | https://www.lcsc.com/product-detail/USB-ICs_WCH-Jiangsu-Qin-Heng-CH340C_C84681.html | LCSC
W25Q32JVSSIQ SPI Flash 32Mb (SOIC-8) | External SPI flash for iCE40 bitstream cold-boot storage. | 2 | 0.55 | 1.10 | https://www.lcsc.com/product-detail/NOR-FLASH_Winbond-Elec-W25Q32JVSSIQ_C179171.html | LCSC
AP2112K-3.3TRG1 LDO 3.3V (SOT-23-5) | 3.3V low-dropout regulator for FPGA VCCIO (I/O banks). 600 mA output. | 2 | 0.30 | 0.60 | https://www.lcsc.com/product-detail/LDO-Voltage-Regulators_Diodes-Incorporated-AP2112K-3-3TRG1_C51118.html | LCSC
AP2112K-1.2TRG1 LDO 1.2V (SOT-23-5) | 1.2V low-dropout regulator for iCE40 core VCC. iCE40HX requires separate 1.2V core supply. | 2 | 0.30 | 0.60 | https://www.lcsc.com/product-detail/LDO-Voltage-Regulators_Diodes-Incorporated-AP2112K-1-2TRG1_C89528.html | LCSC
25 MHz Crystal Oscillator SMD (3225) | Primary clock source for FPGA core. Guard ring on F.Cu. | 2 | 0.35 | 0.70 | https://www.lcsc.com/product-detail/Crystals_YXC-X322532MOB4SI_C32346.html | LCSC
USB Type-C Connector SMD | Power input and USB programming port. CC1/CC2 with 5.1kΩ pull-downs for charger negotiation. | 2 | 0.40 | 0.80 | https://www.lcsc.com/product-detail/USB-Connectors_Korean-Hroparts-Elec-TYPE-C-31-M-12_C165948.html | LCSC
100nF Decoupling Capacitor 0402 (x20) | FPGA power rail decoupling — one per VCC/VCCIO pin per iCE40 datasheet. | 20 | 0.01 | 0.20 | https://www.lcsc.com | LCSC
10uF Bulk Capacitor 0805 (x4) | LDO output filtering and bulk supply stabilization. | 4 | 0.05 | 0.20 | https://www.lcsc.com | LCSC
5.1k Ohm Resistor 0402 (x4) | USB-C CC1/CC2 pull-down resistors. Required for USB-C charger detection. | 4 | 0.01 | 0.04 | https://www.lcsc.com | LCSC
100 Ohm Resistor 0402 (x4) | LED current limiting resistors. | 4 | 0.01 | 0.04 | https://www.lcsc.com | LCSC
LED 0805 (x2) | Power-on and CDONE (bitstream loaded) status indicators. | 2 | 0.05 | 0.10 | https://www.lcsc.com | LCSC
Microchip 23K256 SPI SRAM 256Kb (SOIC-8) | External SPI SRAM for lx32 data memory expansion. 256Kbit / 32KB, 20 MHz max, 1.8–3.6V. SPI/SDI/SQI modes. Pairs with FPGA SPI master. | 2 | 0.60 | 1.20 | https://www.lcsc.com/product-detail/SRAM_Microchip-Tech-23K256-I-SN_C506713.html | LCSC
VGA 2x5 Pin Header 2.54mm (THT) | VGA output connector for lx32 video output. 5 signal pins (R/G/B/HSYNC/VSYNC) + 5 GND. Routes to FPGA GPIO via 68Ω series resistors. | 2 | 0.35 | 0.70 | https://www.lcsc.com | LCSC
68 Ohm Resistor 0402 (x6) | VGA series resistors (R5/R6/R7) — one per colour channel. Limits current into monitor input impedance. | 6 | 0.01 | 0.06 | https://www.lcsc.com | LCSC
2.54mm Pin Headers (40-pos strip) | OLED peripheral header and debug I/O breakout on carrier board. | 1 | 0.80 | 0.80 | https://www.lcsc.com | LCSC
M3 Nylon Standoffs 10mm (x4) | Board mounting — pairs with M3 mounting holes at board corners. | 4 | 0.15 | 0.60 | https://www.lcsc.com | LCSC
M3 Screws + Nuts (x4 each) | Secure board to enclosure or test fixture via MH1-MH4. | 8 | 0.05 | 0.40 | https://www.lcsc.com | LCSC
0.96in OLED Display (SPI/I2C) | CPU status display — shows register values and instruction stream from running lx32 core. | 1 | 14.22 | 14.22 | https://www.amazon.com/pulgadas-pantalla-autoluminosa-compatible-Raspberry/dp/B09T6SJBV5 | Amazon via Tiendamia
Jumper Wires & Breadboard Kit | Peripheral prototyping and OLED bring-up. | 1 | 9.89 | 9.89 | https://www.amazon.com/Prdiozyn-Breadborad001/dp/B0G7CSPV18 | Amazon via Tiendamia
Shipping — JLCPCB to Uruguay (Global Standard Direct) | International shipping for PCB and SMD components. | 1 | 22.00 | 22.00 | - | JLCPCB
Shipping — Tiendamia (OLED + jumpers to Uruguay) | Local logistics for Amazon items via Tiendamia forwarding. | 1 | 38.00 | 38.00 | - | Tiendamia
TOTAL |  |  |  | 127.15

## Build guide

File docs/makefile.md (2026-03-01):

  
Complete reference for LX32 Makefile targets and options.

## Overview

The Makefile automates building and testing the LX32 processor. It handles:

1. Verilator RTL simulation library generation

2. SystemVerilog testbench compilation and execution

3. Cleaning build artifacts

4. Environment configuration

## Makefile Targets

### librust

Generates Verilator C++ library from RTL source.

```bash

make librust

```

**What it does:**

1. Runs Verilator to parse SystemVerilog RTL

2. Generates C++ simulation models

3. Compiles C++ FFI bridge (bridge.cpp)

4. Links everything into lx32_bridge library

**Output:**

- `.sim/lx32_lib/` directory with generated C++ files

- Static library linking to Verilator

**When to use:**

- First-time setup

- After modifying RTL files

- When Verilator installation changes

**Prerequisites:**

- Verilator installed and in PATH

- g++ or clang++ available

**Time:** 10-30 seconds

---

### sim

Compiles and runs a SystemVerilog testbench.

```bash

make sim TB=<testbench_name>

```

**Parameters:**

- `TB`: Testbench name (required)

**Examples:**

```bash

make sim TB=lx32_system_tb # Run lx32_system testbench

make sim TB=alu_tb # Run ALU testbench

```

**What it does:**

1. Creates output directory `.sim/<TB>/`

2. Runs Verilator to compile testbench

3. Generates waveform file (+trace option)

4. Executes simulation

**Output:**

- `<TB>_sim` executable

- `.vcd` waveform file (if +trace flag used)

**When to use:**

- Testing individual RTL modules

- Debugging waveforms

- Verifying RTL before golden model testing

**Prerequisites:**

- Verilator installed

- librust target completed first

**Time:** 5-15 seconds

---

### help

Displays help information.

```bash

make help

```

**Output:**

```

Usage: make sim TB=lx32_system_tb

```

**When to use:**

- Quick reference of available targets

---

### clean

Removes all build artifacts.

```bash

make clean

```

**What it deletes:**

- `.sim/` directory (all generated files and outputs)

- Testbench executables

- Waveform files

**What it preserves:**

- Source files (.sv, .rs, .cpp)

- Documentation

- Cargo artifacts

**When to use:**

- Starting fresh build

- Removing intermediate files

- Before committing to version control

**Time:** < 1 second

---

## Makefile Variables

### SHELL

```makefile

SHELL := /bin/sh

```

Specifies shell for command execution. Use `/bin/sh` for POSIX compatibility.

### VERILATOR

```makefile

VERILATOR ?= verilator

```

Path to Verilator executable. Can be overridden:

```bash

make librust VERILATOR=/opt/verilator/bin/verilator

```

Default: Uses PATH, expects `verilator` command available.

### VERILATOR_FLAGS

```makefile

VERILATOR_FLAGS ?= -Wall -Wno-fatal --binary --trace --trace-structs -O2 --timing

```

Flags passed to Verilator compiler. Meanings:

| Flag | Purpose |

|------|---------|

| `-Wall` | Enable all warnings |

| `-Wno-fatal` | Don't stop on warnings |

| `--binary` | Generate executable |

| `--trace` | Enable VCD waveform output |

| `--trace-structs` | Include struct members in waveforms |

| `-O2` | Optimization level 2 |

| `--timing` | Enable timing simulation |

Custom flags:

```bash

make sim TB=lx32_system_tb VERILATOR_FLAGS="-Wall -O3"

```

### OUTDIR

```makefile

OUTDIR := .sim

```

Output directory for generated files. Default: `.sim/` in project root.

### RTL_CORE

```makefile

RTL_CORE := rtl/core

```

Directory containing core RTL modules.

### RTL_ARCH

```makefile

RTL_ARCH := rtl/arch

```

Directory containing architecture package files.

### TB_CORE

```makefile

TB_CORE := tb/core

```

Directory containing testbenches.

### VALIDATOR_DIR

```makefile

VALIDATOR_DIR := tools/lx32_validator

```

Directory for Rust golden model framework.

### VERILATOR_ROOT

```makefile

VERILATOR_ROOT = /opt/homebrew/Cellar/verilator/5.044/share/verilator

```

Root installation directory for Verilator. Used by build.rs for finding include files.

**For different installations:**

Homebrew (macOS):

```bash

/opt/homebrew/opt/verilator/share/verilator

```

Linux system package:

```bash

/usr/share/verilator

```

Custom location:

```bash

export VERILATOR_ROOT=/custom/path/verilator/share/verilator

make librust

```

### VERILATOR_INC

```makefile

VERILATOR_INC = $(VERILATOR_ROOT)/include

```

Include directory for Verilator headers. Automatically derived from VERILATOR_ROOT.

## Usage Patterns

### Initial Setup

```bash

# 1. Generate RTL library (one-time setup)

make librust

# 2. All subsequent builds use the library

cargo build --release

```

### Quick Test

```bash

# Run single testbench

make sim TB=alu_tb

```

### Clean and Rebuild

```bash

# Remove all artifacts

make clean

# Rebuild from scratch

make librust

```

### Full Cleanup

```bash

# Clean both RTL and Rust artifacts

make clean

cd tools/lx32_validator && cargo clean

cd ../..

```

### Setting Custom Paths

```bash

# Use non-default Verilator

export VERILATOR=/usr/local/bin/verilator

export VERILATOR_ROOT=/usr/local/share/verilator

make librust

```

## Troubleshooting

### Error: "verilator: command not found"

**Problem:** Verilator not in PATH

**Solutions:**

```bash

# Find Verilator

which verilator

# or

find /opt -name verilator

# Set in Makefile or environment

export PATH=$PATH:/path/to/verilator/bin

make librust

# Or specify directly

make librust VERILATOR=/path/to/verilator/bin/verilator

```

### Error: ".sim/lx32_lib not found"

**Problem:** RTL library not generated

**Solution:**

```bash

make librust

make sim TB=lx32_system_tb

```

Ensure librust completes successfully before running sim.

### Error: "Verilog file not found"

**Problem:** RTL source files not found

**Solution:** Check that RTL files exist:

```bash

ls rtl/arch/*.sv

ls rtl/core/*.sv

ls tb/core/lx32_system_tb.sv

```

Update Makefile variables if paths differ:

```makefile

RTL_CORE := /custom/path/rtl/core

```

### Verilator: "lint warnings"

**Problem:** Many lint warnings from RTL

**Current behavior:** Warnings are shown but don't stop compilation (`-Wno-fatal`)

**To make warnings fatal:**

```bash

make sim TB=lx32_system_tb VERILATOR_FLAGS="-Wall -O2"

```

(Remove `-Wno-fatal` to fail on warnings)

### Build hangs or takes very long

**Problem:** Compilation taking too long

**Solutions:**

1. Use optimization level 2 (default):

```makefile

VERILATOR_FLAGS ?= ... -O2 ...

```

2. Reduce verbosity:

```makefile

VERILATOR_FLAGS ?= -Wno-fatal --binary -O2

```

3. Use custom configuration:

```bash

make librust VERILATOR_FLAGS="-Wall -Wno-fatal --binary -O2"

```

## Integration with Rust Build

The Makefile and Rust Cargo system work together:

**Phase 1: Makefile** (RTL compilation via Verilator)

```bash

make librust

-> .sim/lx32_lib/ (C++ simulation)

-> .sim/bridge.o (FFI bridge object)

```

**Phase 2: Cargo** (Rust compilation)

```bash

cargo build --release

build.rs runs:

-> Finds .sim/lx32_lib/

-> Finds VERILATOR_ROOT

-> Compiles bridge.cpp

-> Links all together

-> tools/lx32_validator/target/release/

```

**Phase 3: Execution**

```bash

cargo run --release

-> Links with pre-compiled RTL

-> Runs golden model tests

```

## Optimization Levels

Verilator provides different optimization levels:

| Level | Speed | Build Time | Use case |

|-------|-------|------------|----------|

| O0 | Slow | Fast | Debugging |

| O2 | Fast | Medium | Default (recommended) |

| O3 | Very Fast | Long | Production |

| O4 | Fastest | Very long | High-performance |

Default uses `-O2`:

```makefile

VERILATOR_FLAGS ?= ... -O2 ...

```

Change for different scenarios:

```bash

# Quick iteration (fast build)

make librust VERILATOR_FLAGS="-O0 -Wno-fatal --binary"

# Performance (thorough test)

make librust VERILATOR_FLAGS="-O3 -Wall -Wno-fatal --binary"

```

## Advanced Usage

### Standalone Testbench Compilation

```bash

# Compile only, don't run (debugging)

make librust

verilator -Wall --cc \

--Mdir .sim/lx32_lib \

rtl/arch/*.sv rtl/core/*.sv \

--top-module lx32_system

```

### Custom Testbench Location

```makefile

# Add to Makefile

TB_CUSTOM := path/to/custom/testbenches

sim_custom:

verilator $(VERILATOR_FLAGS) \

--top-module $(TB) \

--Mdir $(OUTDIR)/$(TB) \

$(RTL_ARCH)/*.sv \

$(RTL_CORE)/*.sv \

$(TB_CUSTOM)/$(TB).sv \

-o $(TB)_sim

```

Then use:

```bash

make sim_custom TB=custom_tb

```

### Generating Only C++, Not Running

```bash

# Don't add --binary to stop before compilation

verilator -Wall --cc \

rtl/arch/*.sv rtl/core/*.sv

```

Output in `obj_dir/` (default).

## Performance Tips

### Speed Up Compilation

1. **Use optimization level 2 (default):** Good balance

2. **Disable unnecessary features:**

```bash

make librust VERILATOR_FLAGS="-Wall --binary -O2"

```

3. **Use parallel build:**

```bash

make -j4 librust

```

### Speed Up Simulation

1. **Disable waveform tracing:**

```bash

make sim TB=lx32_system_tb VERILATOR_FLAGS="-Wall -O2 --binary"

```

2. **Use higher optimization:**

```bash

make librust VERILATOR_FLAGS="-Wall --binary -O3"

```

3. **Run release build of Rust tests:**

```bash

cargo run --release

```

## Environment Setup Script

Create `setup.sh` for repeatablebuilds:

```bash

#!/bin/bash

set -e

# Set Verilator paths

export VERILATOR=/usr/local/bin/verilator

export VERILATOR_ROOT=/usr/local/share/verilator

# Build RTL

echo "Building RTL library..."

cd /path/to/lx32

make clean

make librust

# Build and test

echo "Building and testing Rust validator..."

cd tools/lx32_validator

cargo clean

cargo build --release

cargo run --release

echo "All tests passed!"

```

Run with:

```bash

bash setup.sh

```

## File Locations

**Makefile:**

```

/path/to/lx32/Makefile

```

**RTL files:**

```

/path/to/lx32/rtl/arch/*.sv

/path/to/lx32/rtl/core/*.sv

```

**Testbenches:**

```

/path/to/lx32/tb/core/*.sv

```

**Build output:**

```

/path/to/lx32/.sim/

```

**Rust validator:**

```

/path/to/lx32/tools/lx32_validator/

```

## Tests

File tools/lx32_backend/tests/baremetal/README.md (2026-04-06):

# Bare-Metal C Smoke (LX32)

This folder validates the minimum C-freestanding slice for firmware/drivers on LX32:

- assignments and integer arithmetic,
- raw pointer/MMIO loads and stores,
- control flow and direct calls,
- no libc/runtime dependency.

## Programs

- `programs/01_return42.c` - simplest entrypoint.
- `programs/02_pointer_store.c` - pointer dereference load/store.
- `programs/03_call_chain.c` - direct call sequence and return path.
- `programs/04_branch_loop.c` - simple counted loop with branches (currently `XFAIL`).

## Run

```bash
bash /Users/axel/lx32/tools/lx32_backend/tests/baremetal/run_baremetal_smoke.sh
```

## Notes

- Uses `-ffreestanding -fno-builtin -nostdlib`.
- `tests/compile_baremetal_c.sh` always emits `.ll` and `.s`.
- `.o` is attempted and reported as best-effort while MC object emission is
  still being finished.
- Script fails if it detects common libcalls (`__divsi3`, `memcpy`, etc.).
- `04_branch_loop.c` is tracked as expected-fail until branch lowering
  (`br`/`brcond`) is completed in the LX32 lowering/selector path.

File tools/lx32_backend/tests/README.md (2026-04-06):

# LX32 Backend Smoke Tests

This folder contains minimal backend smoke tests for early bring-up.

## Scope

These tests validate the first usable SelectionDAG slice:

- formal argument lowering for fixed-arg integer functions,
- return lowering,
- DAG selector wiring in `LX32TargetMachine`.

It also contains a bare-metal C smoke slice for firmware-focused bring-up.

## Run

```bash
bash /Users/axel/lx32/tools/lx32_backend/tests/run_smoke.sh /path/to/llc
```

If no argument is provided, the script tries:

- `/Users/axel/llvm-project/build/bin/llc`
- `llc` from `PATH`

## Notes

- These are bring-up checks, not full `lit` tests yet.
- They only require `-filetype=asm`.
- If your `llc` binary points at a different LX32 source checkout, failures may
  reflect checkout mismatch rather than this workspace.

## Bare-Metal C smoke

Run:

```bash
bash /Users/axel/lx32/tools/lx32_backend/tests/baremetal/run_baremetal_smoke.sh
```

This validates the freestanding C path (`clang -> llc -march=lx32`) for:

- plain integer arithmetic,
- pointer/MMIO loads and stores,
- direct calls and returns,
- no implicit libcalls.

Current expected status: three PASS cases (`return42`, `call_chain`,
`pointer_store`) and one tracked XFAIL (`branch_loop`).

## What is still missing for executing C end-to-end

- `core/LX32FrameLowering.cpp` still has empty prologue/epilogue emission,
  so non-leaf calls do not preserve `ra` safely yet.
- MC/object emission for a full `-filetype=obj` pipeline is not complete in
  this workspace cut, so linking/running ELF binaries is not ready.

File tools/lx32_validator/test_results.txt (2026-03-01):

================================== LX32 FULL HARDWARE VALIDATION ===================================

=================================== STARTING CONTROL UNIT FUZZER ===================================
Iterations: 500
Registers: (0, 32)
Immediates: (-2048, 2047)
[    0] Instr: 0xd2a43a13 | PC: [R:0x0004 G:0x0004] | x20(RD): [R:0x00000001 G:0x00000000] | ✗ MISMATCH

================================== CONTROL UNIT MISMATCH DETECTED ==================================
Iteration: 0
Instruction: 0xd2a43a13

RTL State:
  PC: 0x0004
  x20 (RD): 0x00000001
  x 8 (RS1): 0x00000000
  x10 (RS2): 0x00000000

Golden State:
  PC: 0x0004
  x20 (RD): 0x00000000
  x 8 (RS1): 0x00000000
  x10 (RS2): 0x00000000

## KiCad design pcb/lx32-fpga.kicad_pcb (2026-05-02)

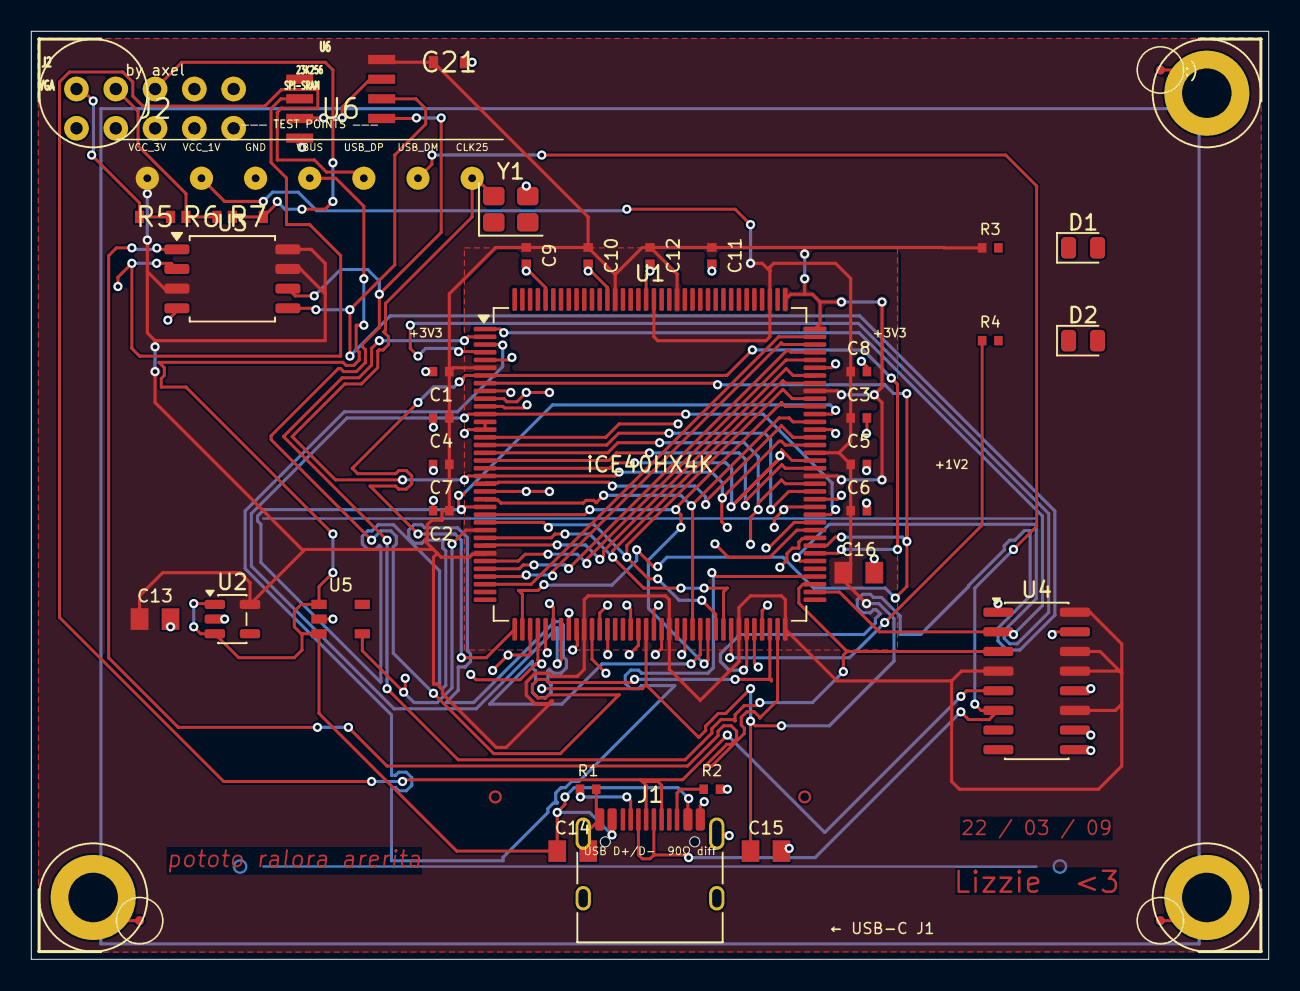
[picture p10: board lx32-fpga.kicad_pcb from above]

Board: 4 copper layers, 80.0 x 60.0 mm, 49 parts (0 on the bottom side), 45 nets.

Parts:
C1, C2, C3, C4, C5, C6, C7, C8, C9, C10, C11, C12: 100nF; C_0402_1005Metric
C13, C14, C15, C16: 10uF; C_0805_2012Metric
C21: 100nF
D1, D2: LED; LED_0805_2012Metric
FID1, FID2, FID3: Fiducial
J1: USB_C_Receptacle_USB2.0_14P; USB_C_Receptacle
J2: VGA_HDR
MH1, MH2, MH3, MH4: MH_M3
R1, R2: 5.1k; R_0402_1005Metric
R3, R4: 100R; R_0402_1005Metric
R5, R6, R7: 68R
TP1: VCC_3V3
TP2: VCC_1V2
TP3: GND
TP4: VBUS
TP5: USB_DP
TP6: USB_DM
TP7: CLK25
U1: ICE40HX4K-TQ144; TQFP-144_20x20mm_P0.5mm
U2: AP2112K-3.3; SOT-23-5
U3: W25Q32JVSS; SOIC-8_5.3x5.3mm_P1.27mm
U4: CH340C; SOIC-16_3.9x9.9mm_P1.27mm
U5: AP2112K-1.2; SOT-23-5
U6: 23K256
Y1: Crystal; Crystal_SMD_3225-4Pin

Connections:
CC1: J1.A5 (CC1), R1.1
CC2: J1.B5 (CC2), R2.1
CDONE: R4.1, U1.65 (CDONE)
CLK25: TP7.1, U1.20 (IOL_13B_GBIN7), U1.52 (IOB_82_GBIN4), U1.93 (IOR_140_GBIN3), Y1.4
GND: C1.2, C2.2, C3.2, C4.2, C5.2, C6.2, C7.2, C8.2, C9.2, C10.2, C11.2, C12.2, C13.2, C14.2, C15.2, C16.2, C21.2, FID1.1, FID2.1, J1.A1 (GND), J1.A12 (GND), J1.B1 (GND), J1.B12 (GND), J1.SH (SHIELD), J2.6, J2.7, J2.8, J2.9, J2.10, MH2.1, MH3.1, MH4.1, R1.2, R2.2, TP3.1, U1.5 (GND), U1.13 (GND), U1.14 (GND), U1.53 (GNDPLL0), U1.59 (GND), U1.69 (GND), U1.86 (GND), U1.103 (GND), U1.127 (GNDPLL1), U1.132 (GND), U1.140 (GND), U2.2 (GND), U3.4 (GND), U4.1 (GND), U4.9 (~CTS), U4.10 (~DSR), U4.12 (~DCD), U4.15 (R232), U5.2, U6.4, Y1.3
unnamed: U1.3 (IOL_3A), U1.76 (IOR_112)
unnamed: U1.4 (IOL_3B), U1.78 (IOR_114)
unnamed: U1.7 (IOL_4A), U1.37 (IOB_56), U1.79 (IOR_115)
unnamed: U1.8 (IOL_4B), U1.38 (IOB_57), U1.80 (IOR_116)
unnamed: U1.9 (IOL_5A), U1.39 (IOB_61), U1.81 (IOR_117)
unnamed: U1.10 (IOL_5B), U1.41 (IOB_63), U1.82 (IOR_118)
unnamed: U1.11 (IOL_8A), U1.42 (IOB_64), U1.83 (IOR_119)
unnamed: U1.12 (IOL_8B), U1.43 (IOB_71), U1.84 (IOR_120)
unnamed: U1.15 (IOL_10A), U1.44 (IOB_72), U1.85 (IOR_128)
unnamed: U1.16 (IOL_10B), U1.45 (IOB_73), U1.87 (IOR_136)
unnamed: U1.17 (IOL_12A), U1.47 (IOB_79), U1.88 (IOR_137)
unnamed: U1.18 (IOL_12B), U1.48 (IOB_80), U1.90 (IOR_138)
unnamed: U1.19 (IOL_13A), U1.49 (IOB_81_GBIN5), U1.91 (IOR_139)
unnamed: U1.21 (IOL_14A_GBIN6), U1.55 (IOB_91), U1.94 (IOR_141_GBIN2)
unnamed: U1.22 (IOL_14B), U1.56 (IOB_94), U1.95 (IOR_144)
unnamed: U1.23 (IOL_17A), U1.60 (IOB_95), U1.96 (IOR_146)
unnamed: U1.24 (IOL_17B), U1.61 (IOB_96), U1.97 (IOR_147)
unnamed: U1.25 (IOL_18A), U1.62 (IOB_102), U1.98 (IOR_148)
unnamed: U1.26 (IOL_18B), U1.63 (IOB_103_CBSEL0), U1.99 (IOR_152)
unnamed: U1.28 (IOL_23A), U1.64 (IOB_104_CBSEL1), U1.101 (IOR_160)
unnamed: U1.29 (IOL_23B), U1.102 (IOR_161)
unnamed: U1.31 (IOL_24A), U1.104 (IOR_164)
unnamed: U1.32 (IOL_24B), U1.105 (IOR_165)
unnamed: U1.33 (IOL_25A), U1.106 (IOR_166)
unnamed: U1.34 (IOL_25B), U1.107 (IOR_167)
SPI_CLK: U1.70 (IOB_107_SCK), U3.6 (CLK), U6.5
SPI_MISO: U1.68 (IOB_106_SDI), U3.2 (DO/IO_{1}), U6.2
SPI_MOSI: U1.67 (IOB_105_SDO), U3.5 (DI/IO_{0}), U6.6
SPI_SS: U1.71 (IOB_108_SS), U3.1 (~CS)
SRAM_HOLD: U6.3, U6.7
UART_RX: U1.2 (IOL_2B), U1.75 (IOR_111), U4.3 (RXD)
UART_TX: U1.1 (IOL_2A), U1.74 (IOR_110), U4.2 (TXD)
USB_DM: J1.A7 (D-), J1.B7 (D-), TP6.1, U4.6 (UD-)
USB_DP: J1.A6 (D+), J1.B6 (D+), TP5.1, U4.5 (UD+)
VBUS: C14.1, J1.A4 (VBUS), J1.A9 (VBUS), J1.B4 (VBUS), J1.B9 (VBUS), TP4.1, U2.1 (VIN), U2.3 (EN), U5.1, U5.3
VCC_1V2: C3.1, C5.1, C6.1, C8.1, C15.1, C16.1, TP2.1, U1.27 (VCC), U1.40 (VCC), U1.54 (VCCPLL0), U1.92 (VCC), U1.111 (VCC), U1.126 (VCCPLL1), U5.5
VCC_3V3: C1.1, C2.1, C4.1, C7.1, C9.1, C10.1, C11.1, C12.1, C13.1, C21.1, R3.1, TP1.1, U1.6 (VCCIO_3), U1.30 (VCCIO_3), U1.46 (VCCIO_2), U1.57 (VCCIO_2), U1.66 (~CRESET), U1.72 (VCC_SPI), U1.89 (VCCIO_1), U1.100 (VCCIO_1), U1.108 (VPP_2V5), U1.109 (VPP_FAST), U1.123 (VCCIO_0), U1.131 (VCCIO_0), U2.5 (VOUT), U3.3 (~WP/IO_{2}), U3.7 (~HOLD/~RESET/IO_{3}), U3.8 (VCC), U4.4 (V3), U4.11 (~RI), U4.13 (~DTR), U4.14 (~RTS), U4.16 (VCC), U6.8
VGA_B: J2.3, R7.1, R7.2
VGA_G: J2.2, R6.1, R6.2
VGA_R: J2.1, R5.1, R5.2

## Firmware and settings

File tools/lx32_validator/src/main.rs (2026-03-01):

// src/main.rs
#[path = "../tests/test_alu.rs"]
mod test_alu;

#[path = "../tests/test_branch_unit.rs"]
mod test_branch_unit;

#[path = "../tests/test_control_unit.rs"]
mod test_control_unit;

#[path = "../tests/test_lsu.rs"]
mod test_lsu;

#[path = "../tests/test_imm_gen.rs"]
mod test_imm_gen;

#[path = "../tests/test_memory_sim.rs"]
mod test_memory_sim;

#[path = "../tests/test_reg_generic.rs"]
mod test_reg_generic;

#[path = "../tests/test_register_file.rs"]
mod test_register_file;

#[path = "../tests/test_lx32_system.rs"]
mod test_lx32_system;

fn main() {
    println!("{:=^100}", " LX32 FULL HARDWARE VALIDATION ");

    // ALU validation
    test_alu::run_alu_fuzzer(test_alu::AluTestParams {
        iterations: 3000,
        rd_range: (1, 32),
        rs1_range: (0, 32),
        imm_range: (0, 4096),
        enable_logging: false,
    });

    // Branch validation
    test_branch_unit::run_branch_fuzzer(test_branch_unit::BranchTestParams {
        iterations: 10000,
        reg_range: (0, 32),
        offset_word_range: (-128, 128),
        enable_logging: false,
    });

    // Control Unit validation
    test_control_unit::run_control_unit_fuzzer(test_control_unit::ControlUnitTestParams {
        iterations: 500,
        reg_range: (0, 32),
        imm_range: (-2048, 2047),
        enable_logging: false,
    });

    // LSU validation
    test_lsu::run_lsu_fuzzer(test_lsu::LsuTestParams {
        iterations: 2000,
        reg_range: (0, 32),
        imm_range: (-2048, 2047),
        enable_logging: false,
    });

    // IMM_GEN validation
    test_imm_gen::run_imm_gen_fuzzer(test_imm_gen::ImmGenTestParams {
        iterations: 2000,
        rd_range: (1, 32),
        branch_offset_range: (-1024, 1024),
        i_imm_range: (-2048, 2047),
        s_imm_range: (-2048, 2047),
        enable_logging: false,
    });

    // Memory simulation validation
    test_memory_sim::run_memory_sim_fuzzer(test_memory_sim::MemorySimTestParams {
        iterations: 1000,
        addr_range: (0, 4096),
        data_range: (0, u32::MAX),
        enable_logging: false,
    });

    // Register generic validation
    test_reg_generic::run_reg_generic_fuzzer(test_reg_generic::RegGenericTestParams {
        iterations: 2000,
        data_range: (0, u32::MAX),
        enable_logging: false,
    });

    // Register file validation
    test_register_file::run_register_file_fuzzer(test_register_file::RegisterFileTestParams {
        iterations: 2000,
        reg_range: (0, 32),
        data_range: (0, u32::MAX),
        enable_logging: false,
    });

    // LX32 System validation
    test_lx32_system::run_lx32_system_fuzzer(test_lx32_system::LX32SystemTestParams {
        iterations: 500,
        reg_range: (0, 32),
        imm_range: (-2048, 2047),
        enable_logging: false,
    });

    println!("{:=^100}", " ALL TESTS PASSED SUCCESSFULLY ");
}

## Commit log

2026-02-10 feat(core): implement immediate generator using unique case
2026-04-04 Feat/llvm refactor (#78)
    * feat: added Subtarget in the script to generate an .inc file
    * feat: add minimal Subtarget and TargetMachine stubs
    - Register Subtarget/TargetMachine sources in LX32CodeGen CMake target
    - Provide minimal buildable LX32Subtarget and LX32TargetMachine skeletons
    - Add placeholder headers for lowering/frame/reg/instr info (stubs)
    * feat: reorganize CMakeLists to streamline target structure
    * feat: add missing newline at end of CMakeLists.txt
    * feat: enhance LX32FrameLowering.h with detailed documentation and stub implementations
    * feat: enhance LX32InstrInfo.h with comprehensive documentation and structure
    * feat: enhance LX32ISelLowering.h with detailed documen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
2026-04-23 Enhance README with hardware design and assembly info (#90)
    Updated README to include hardware design details and CAD model information.
2026-04-23 Change image reference in README for CAD model (#92)
    Updated image reference for the hardware block model in the README.
2026-04-23 Add assembly generation script for FreeCAD (#91)
2026-04-23 Add files via upload (#94)
    [Assembly.STEP-Shape.step]
2026-04-23 Update CAD export file path in README (#95)
2026-04-23 Add files via upload (#98)
    [lx32-bom.csv]
2026-04-26 add custom FPGA carrier PCB — iCE40HX4K-TQ144, full KiCad design, gerbers, STEP (#99)
    Custom-designed 2-layer FPGA carrier board for lx32. Designed from scratch in
    KiCad around the Lattice iCE40HX4K-TQ144. This replaces the previously mentioned
    premade dev board approach — everything here is hand-designed.
    Board specs:
    - 80×60mm, 2-layer FR4, ENIG surface finish, black soldermask
    - iCE40HX4K-TQ144 (3.5K LUTs, 80KB BRAM) — enough headroom for lx32 single-cycle core
    - CH340C USB-UART for programming (avoids FTDI driver issues on Linux)
    - W25Q32JV SPI flash for bitstream cold-boot storage
    - Dual LDO rails: AP2112K-3.3V for VCCIO, AP2112K-1.2V for core VCC (separate
    rail required — f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
    [Assembly.STEP-Shape.step, lx32-bom.csv, lx32-fpga.kicad_pcb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]
2026-04-26 add custom FPGA carrier PCB — iCE40HX4K-TQ144, full KiCad design, gerbers, STEP (#102)
    rail required —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
2026-05-02 refactor(submission): lx32 full pcb:) (#103)
    [lx32-bom.csv, lx32-fpga.kicad_pcb]
2026-05-02 [ImgBot] Optimize images (#104)
    *Total -- 3,178.53kb -> 1,705.28kb (46.35%)
    /pcb_front_3d.png -- 265.98kb -> 116.97kb (56.02%)
    /pcb_back_3d.png -- 216.65kb -> 99.19kb (54.22%)
    /pcb_long.png -- 480.47kb -> 256.31kb (46.65%)
    /pcb_first_look.png -- 650.92kb -> 349.50kb (46.31%)
    /pcb_width.png -- 598.01kb -> 325.08kb (45.64%)
    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
2026-05-09 chore: changed the bom to match the csv with the readme (#105)
    [lx32-bom.csv]
2026-05-14 Review/feedback (#106)
    * chore: changed the bom to match the csv with the readme
    * feat: added the png schematics
2026-05-14 [ImgBot] Optimize images (#107)
    /schematics.png -- 894.02kb -> 521.44kb (41.67%)
